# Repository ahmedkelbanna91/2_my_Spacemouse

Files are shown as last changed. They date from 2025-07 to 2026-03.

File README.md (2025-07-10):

# 2_my_Spacemouse
  This ia the best and most interesting project I have been working on. It is a combination of reverse engineering, modification and development of the Spacemouse from 3Dconnexion. I designed the body and this is the code that reads all data from sensors and buttons then send it to the 3DxWare software to use it as same as the original spacemouse compact.

  It is based on Waveshare Esp32S3 Zero board.

  ##Based on this https://github.com/AndunHH/spacemouse

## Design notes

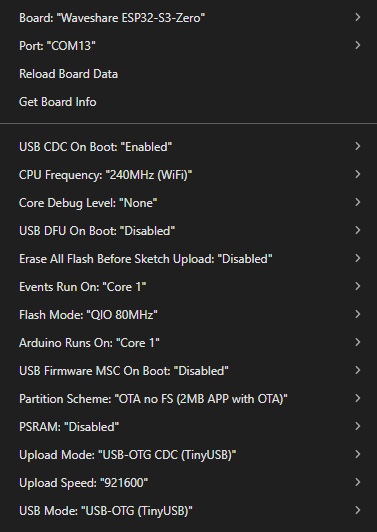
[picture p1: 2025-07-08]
config.jpg

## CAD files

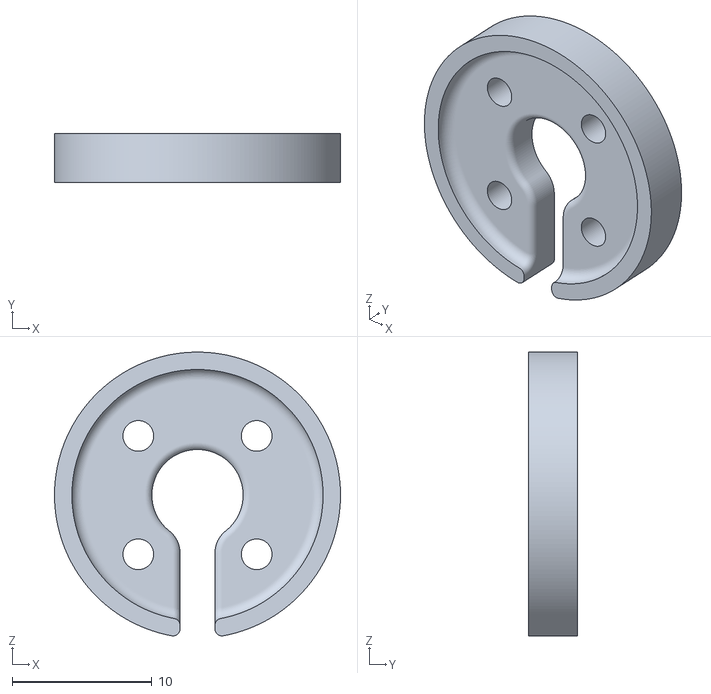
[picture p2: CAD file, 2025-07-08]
3D_Printable_Design_Files/topHolder spacer.stl
20.5 x 3.50 x 20.3

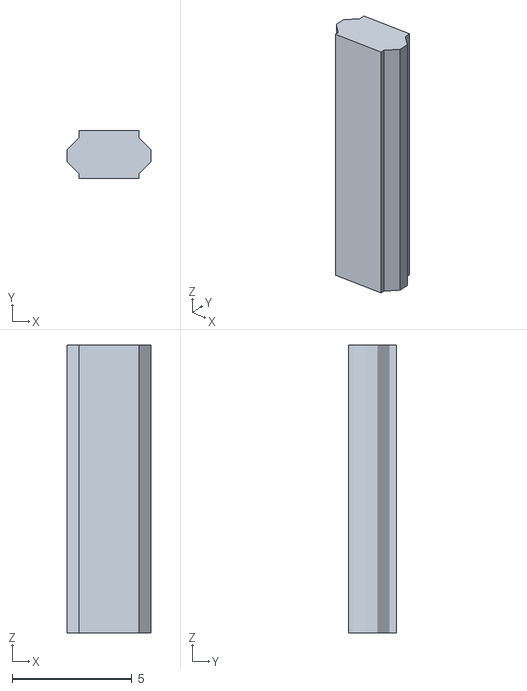
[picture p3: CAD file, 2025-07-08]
3D_Printable_Design_Files/wire-cover.stl
3.50 x 2.00 x 12.0

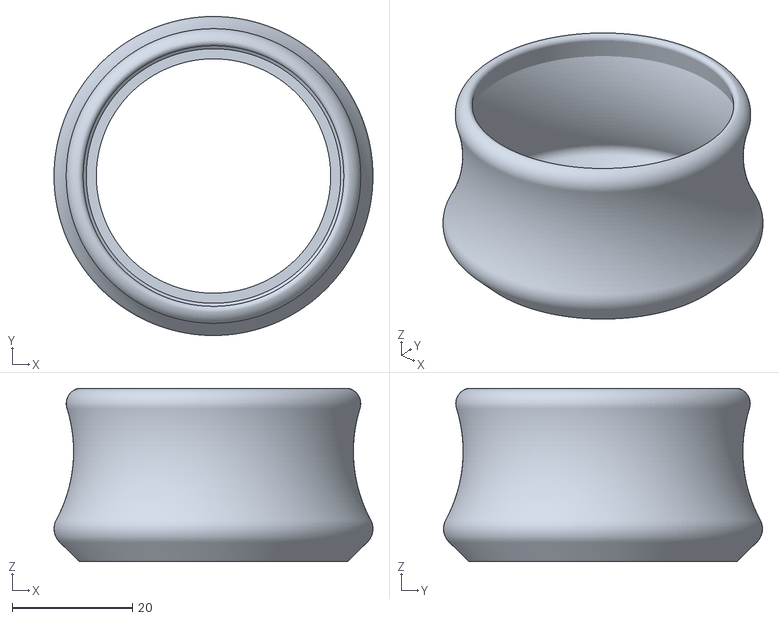
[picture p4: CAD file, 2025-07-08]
3D_Printable_Design_Files/Rubber-Knop.stl
53.1 x 53.1 x 28.8

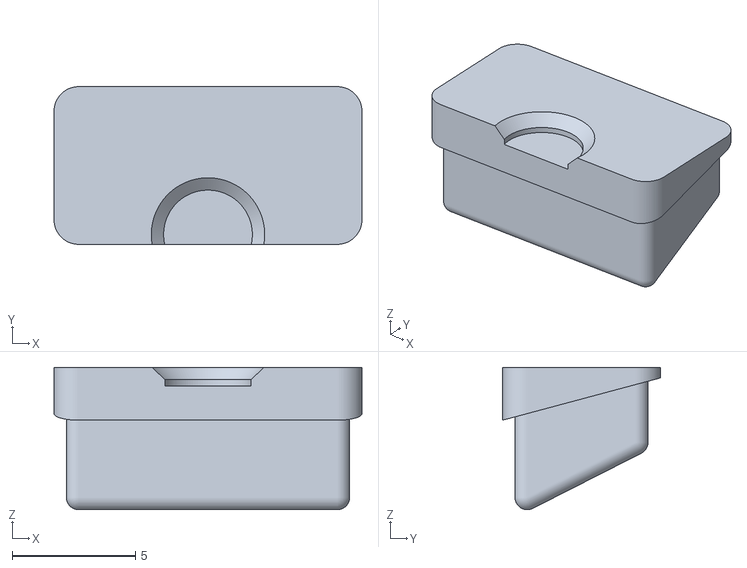
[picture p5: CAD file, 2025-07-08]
3D_Printable_Design_Files/back-btn.stl
12.5 x 6.40 x 5.78

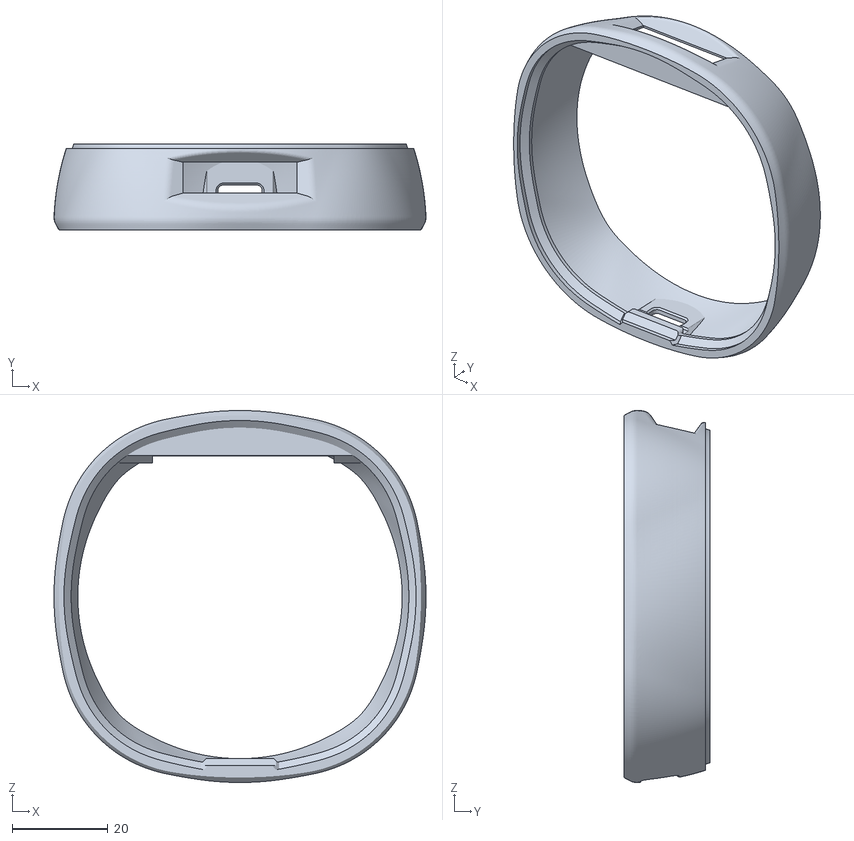
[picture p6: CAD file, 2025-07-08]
3D_Printable_Design_Files/bottom-body.stl
77.9 x 18.1 x 77.9

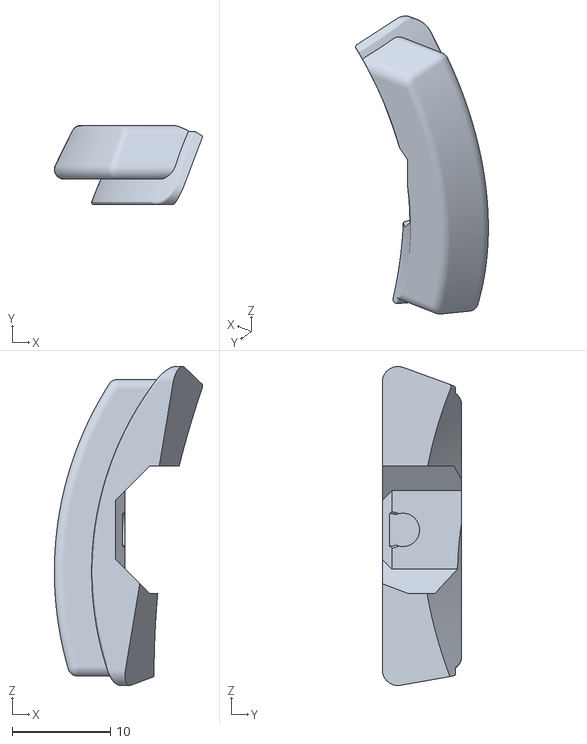
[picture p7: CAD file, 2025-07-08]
3D_Printable_Design_Files/right-btn.stl
15.1 x 8.10 x 32.5

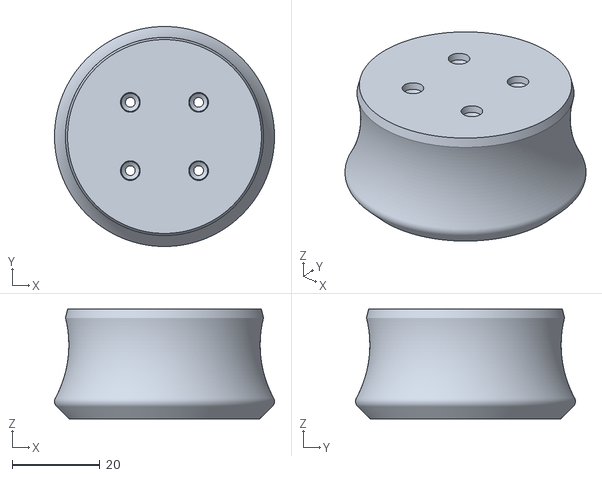
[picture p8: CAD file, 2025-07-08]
3D_Printable_Design_Files/Knop.stl
50.1 x 50.1 x 25.0

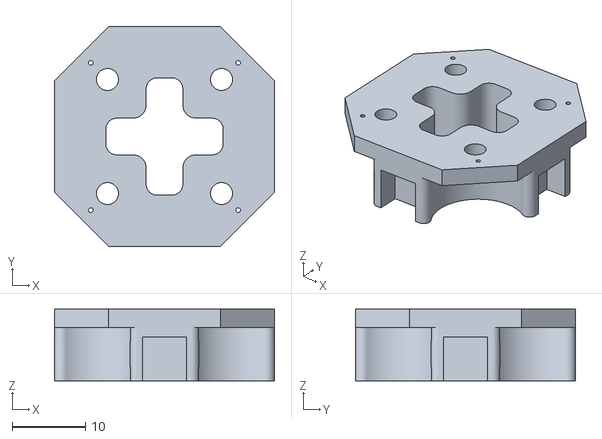
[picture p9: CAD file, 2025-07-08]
3D_Printable_Design_Files/top2.stl
30.0 x 30.0 x 9.80

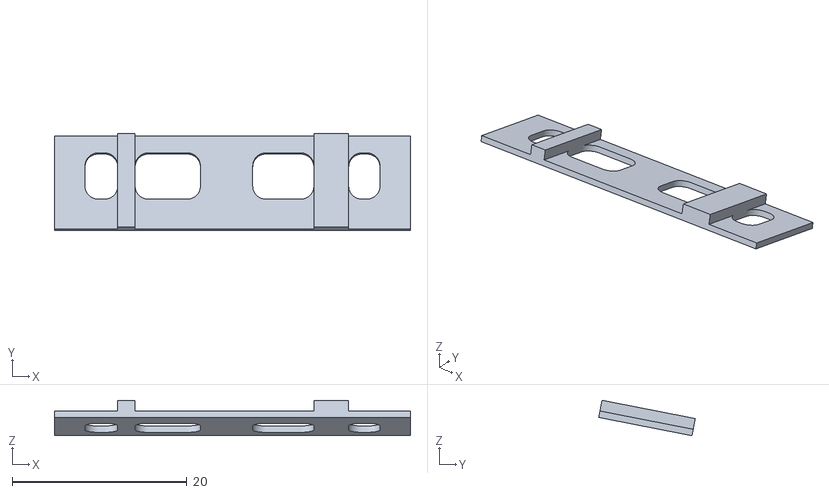
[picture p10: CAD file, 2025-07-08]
3D_Printable_Design_Files/lcd-fixer.stl
40.8 x 11.1 x 4.06

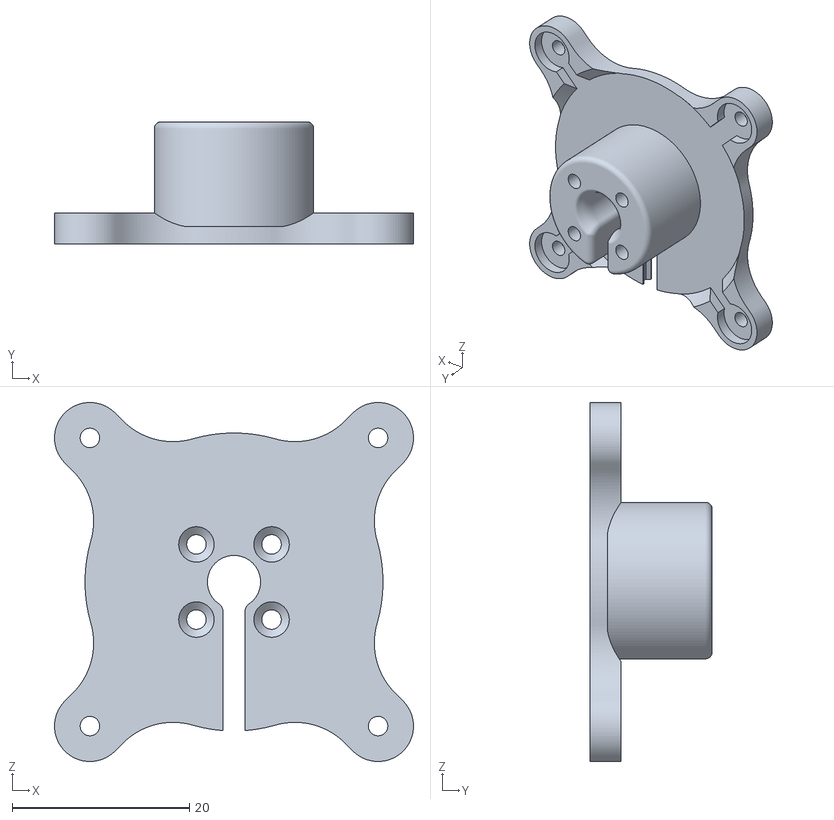
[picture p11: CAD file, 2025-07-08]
3D_Printable_Design_Files/top-holder.stl
40.5 x 13.8 x 40.5

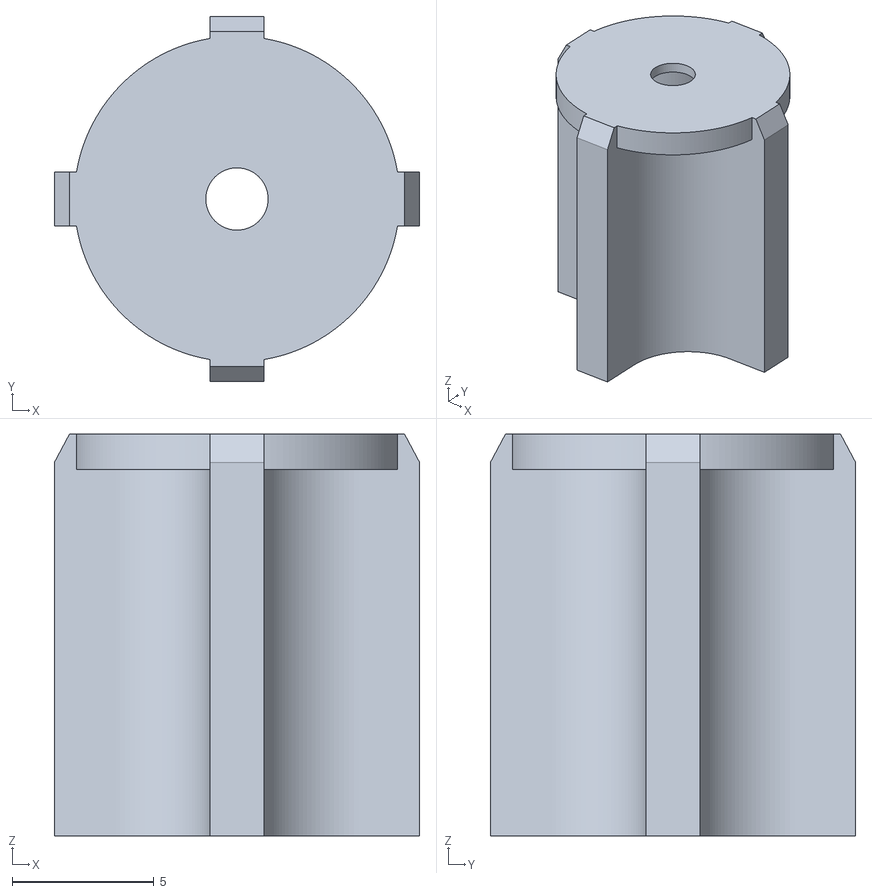
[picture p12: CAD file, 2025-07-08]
3D_Printable_Design_Files/mid2.stl
12.9 x 12.9 x 14.2

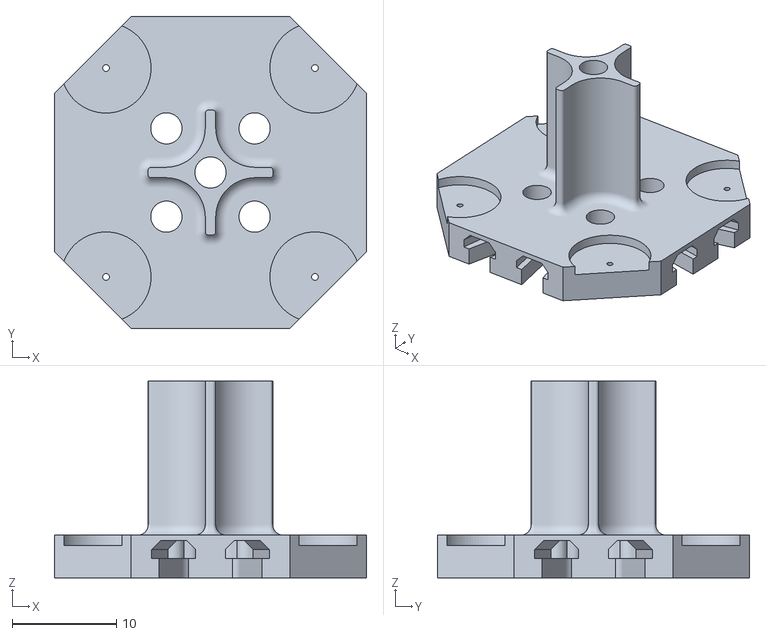
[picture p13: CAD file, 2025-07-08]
3D_Printable_Design_Files/bottom2.stl
30.0 x 30.0 x 18.9

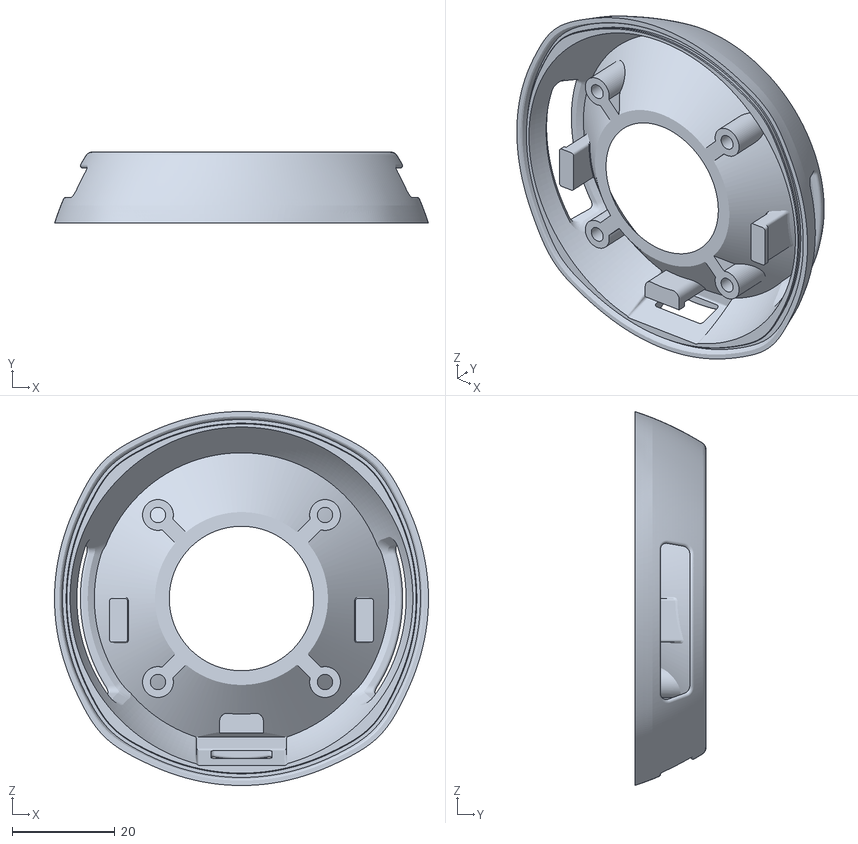
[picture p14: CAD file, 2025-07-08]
3D_Printable_Design_Files/top-body.stl
72.8 x 13.9 x 72.8

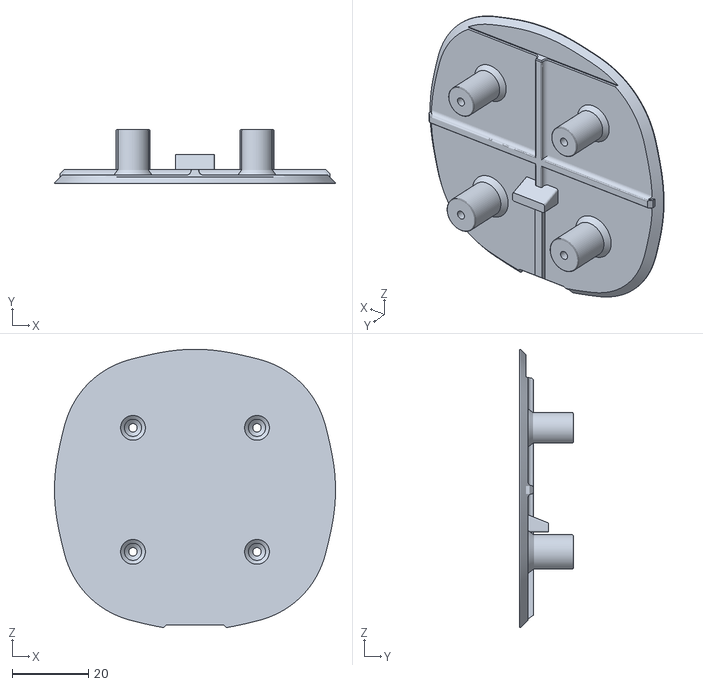
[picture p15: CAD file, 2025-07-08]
3D_Printable_Design_Files/bottom-body-cover.stl
73.7 x 14.1 x 73.0

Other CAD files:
3D_Printable_Design_Files/Left-btn.stl
3D_Printable_Design_Files/knop cover.stl
3D_Printable_Design_Files/esp32-fixer.stl
3D_Printable_Design_Files/Rubber-Knop (1).stl

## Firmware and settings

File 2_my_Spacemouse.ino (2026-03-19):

// #include "Arduino.h"
#include "config.h"
#include "screen.h"
#include "usbSpaceHID.h"
#include "kinematics.h"
#include "calibration.h"
#include "spaceKeys.h"



#ifdef LEDpin
#include "ledring.h"
#endif


// the debug mode can be set during runtime via the serial interface. See config.h for a description of the different debug modes.
int debug = STARTDEBUG;
bool doOnce = true;

// stores the raw analog values from the joysticks
int rawReads[8];

// Centerpoints store the zero position of the joysticks
int centerPoints[8];

// stores the values from the joysticks after zeroing and mapping
int centered[8];

// store raw value of the keys, without debouncing
int keyVals[NUMKEYS];

// key event, after debouncing. It is 1 only for a single sample
uint8_t keyOut[NUMKEYS];
// state of the key, which stays 1 as long as the key is pressed
uint8_t keyState[NUMKEYS];

// Resulting calculated velocities / movements
// int16_t to match what the HID protocol expects.
int16_t velocity[6];



void setup() {
  setupDisplay();
  setupUSB();
  showBootscreen();

  analogReadResolution(analogRead_Resolution);

  setupkalmanFilters();
  busyZeroing(centerPoints, 500, true);
#ifdef LEDpin
  initLEDring();
#endif
  busyZeroing(centerPoints, 3000, true);

  if (!HID.ready()) {
    delay(1);
    return;
  }

// setup the keys e.g. to internal pull-ups
#if NUMKEYS > 0
  setupKeys();
#endif
}

void loop() {
  // check if the user entered a debug mode via serial interface
  if (SERIAL.available()) {
    int tmpInput = SERIAL.parseInt();  // Read from serial interface, if a new debug value has been sent. Serial timeout has been set in setup()
    if (tmpInput != 0) {
      debug = tmpInput;
      if (tmpInput == -1) {
        SERIAL.println(F("Please enter the debug mode now or while the script is reporting."));
      }
    }
  }

  // Joystick values are read. 0-1023
  readAllFromSensors(rawReads);

#if NUMKEYS > 0
  // LivingTheDream added reading of key presses
  readAllFromKeys(keyVals);
#endif
  // Report back 0-1023 raw ADC 10-bit values if enabled
  if (debug == 1) debugOutput1(rawReads, keyVals);

  if (debug == 11 || doOnce) {
    // calibrate the joystick
    // As this is called in the debug=11, we do more iterations.
    busyZeroing(centerPoints, 3000, true);
    debug = -1;  // this only done once
    doOnce = false;
  }

  // Subtract centre position from measured position to determine movement.
  for (int i = 0; i < 8; i++) {
    centered[i] = rawReads[i] - centerPoints[i];
  }

  if (debug == 12) calcMinMax(centered);  // debug=12 to calibrate MinMax values

  // Report centered joystick values if enabled. Values should be approx -500 to +500, jitter around 0 at idle
  if (debug == 2) debugOutput2(centered, keyVals);

  FilterAnalogReadOuts(centered);

  // Report centered joystick values. Filtered for deadzone. Approx -350 to +350, locked to zero at idle
  if (debug == 3) debugOutput2(centered, keyVals);

  calculateKinematic(centered, velocity);

#if NUMKEYS > 0
  evalKeys(keyVals, keyOut, keyState, debug);
#endif

  // Report translation and rotation values if enabled.
  if (debug == 4) debugOutput4(velocity, keyOut);
  if (debug == 5) debugOutput5(centered, velocity);

    // if the kill-key feature is enabled, rotations or translations are killed=set to zero
#if (NUMKILLKEYS == 2)
  // check for the raw keyVal and not keyOut, because keyOut is only 1 for a single iteration. keyVals has inverse Logic due to pull-ups
  // kill rotation
  if (keyVals[KILLROT] == LOW) {
    velocity[ROTX] = 0;
    velocity[ROTY] = 0;
    velocity[ROTZ] = 0;
  }
  // kill translation
  if (keyVals[KILLTRANS] == LOW) {
    velocity[TRANSX] = 0;
    velocity[TRANSY] = 0;
    velocity[TRANSZ] = 0;
  }
#endif

  // report velocity and keys after possible kill-key feature
  if (debug == 6) debugOutput4(velocity, keyOut);

#if SWITCHYZ > 0
  switchYZ(velocity);
#endif

#ifdef EXCLUSIVEMODE
  // exclusive mode
  // rotation OR translation, but never both at the same time
  // to avoid issues with classics joysticks
  exclusiveMode(velocity);
#endif

  // report velocity and keys after Switch or ExclusiveMode
  if (debug == 61) debugOutput4(velocity, keyOut);

  displayScreen(-velocity[ROTX], -velocity[ROTY], velocity[ROTZ],
                velocity[TRANSX], -velocity[TRANSY], -velocity[TRANSZ],
                keyState);

  // update and report the at what frequency the loop is running
  if (debug == 7) updateFrequencyReport();


  // get the values to the USB HID driver to send if necessary
  if (CheckKey3(keyState[2], debug)) sendUSBData(velocity[ROTX], velocity[ROTY], velocity[ROTZ],
                                                 velocity[TRANSX], velocity[TRANSY], velocity[TRANSZ],
                                                 keyState, debug);

  SpaceMouseHID.sendBattery(10, true);

  checkCalibrationCMD(SpaceMouseHID.getLed(), velocity);
}  // end loop()

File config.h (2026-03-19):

/* Calibration instructions
============================
Follow this file from top to bottom to calibrate your space mouse.
You can find some pictures for the calibration process here:
https://github.com/AndunHH/spacemouse/wiki/Ergonomouse-Build#calibration

Debugging Instructions
=========================
To activate one of the following debugging modes, you can either:
- Change STARTDEBUG here in the code and compile again or
- Compile and upload your program. Change to the serial monitor and type the number and hit enter to select the debug mode.

Debug Modes:
------------
-1: Debugging off. Set to this once everything is working.
0:  Nothing...

1:  Output raw joystick values. 0-analogMax_Resolution raw ADC 10-bit values
11: Calibrate / Zero the Spacemouse and get a dead-zone suggestion (This is also done on every startup in the setup())
12: semi-automatic min-max calibration. (Replug/reset the mouse, to enable the semi-automatic calibration for a second time.)
20: print send usb Payload (trans and rot)
21: print send usb Payload (trans)
22: print send usb Payload (rot)
23: print 3rd button send data state
24: print which button is pressed
2:  Output centered joystick values. Values should be approximately -500 to +500, jitter around 0 at idle.
3:  Output centered joystick values. Filtered for deadzone. Approximately -350 to +350, locked to zero at idle, modified with a function.
4:  Output translation and rotation values. Approximately -350 to +350 depending on the parameter.
5:  Output debug 4 and 5 side by side for direct cause and effect reference.
6:  Report velocity and keys after possible kill-key feature
61: Report velocity and keys after kill-switch or ExclusiveMode
7:  Report the frequency of the loop() -> how often is the loop() called in one second?
8:  Report the bits and bytes send as button codes
*/
#define STARTDEBUG 0  // Can also be set over the serial interface, while the program is running!


/* First Calibration: Hall effect sensors pin assignment
==============================================
Default assembly when looking from above on top of the space mouse
 *
 *    back(USB)     resulting axis (not from the single sensors)
 *
 *      7   6              Y+
 *        |                .
 *   8    |    3           .
 *     ---+---        X-...Z+...X+
 *   9    |    2           .
 *        |                .
 *      0   1              Y-
 *

Each sensor is affected by the position of the magnet. If the magnet moves closer to the sensor the output values should decrease.
If you have mounted the magnets upside-down, the values will be inverted.

1. Try to write down the each HES sensor with the corresponding pin number you chose. If you use the PCB version, the pins are shown
   on the silk screen.
2. Compile the script, type 1 into the serial interface and hit enter to enable debug output 1.
3. With the spacemouse in front of you (ie. USB connection at the backside ie. @ north), move the knob from south to north and observe the debug output:
  3.a) HES1 & HES2 both increase when moving the knob north (magnets further away) and decrease when moving the knob south -> Everything is correct.
  3.b) HES1 & HES2 both decrease when moving the knob south (magnets closer by) -> Everything is correct.
  3.c) The sensorpair acts in the opposite direction (ie. increasing when the magnets get closer by ). You probably have mixed up the poles of the magnets.
       Invert the sensorpair in the INVERTLIST.
  3.c) Another output is showing movement: Swap the pins in the PINLIST. This shouldn't happen when the PCB is used. Debugging is rather difficult when
       the spacemouse is assembled, due to the fact that all sensors act on the same movement.

4. Continue with the other sensor pairs. Moving the magnet closer to the sensor should decrease the value.

5. Optimally when not moving the knob, all sensors should output approximately the same value. You can adjuist the values a little bit
   by adjusting the height of the sensor plate using the spacernuts.

5. Repeat this with every axis and every sensor pair until you have a valid PINLIST and maybe an INVERTLIST
*/

// HES1, HES2, HES3, HES4, HES5, HES6, HES7, HES8

// --- Sensor Pin Definitions ---
// ---------M---------
// -------7---6-------
// --7-------------5--
// M-----------------M
// --8-------------4--
// -------1---2-------
// ---------M---------

#define HES1_PIN 6   // Bottom Pair, Sensor 1, left
#define HES2_PIN 7   // Bottom Pair, Sensor 2, right
#define HES3_PIN 8   // Right Pair, Sensor 3, bottom
#define HES4_PIN 9   // Right Pair, Sensor 4, top
#define HES5_PIN 10  // Top Pair, Sensor 5, right
#define HES6_PIN 11  // Top Pair, Sensor 6, left
#define HES7_PIN 12  // Left Pair, Sensor 7, top
#define HES8_PIN 13  // Left Pair, Sensor 8, bottom

#define analogRead_Resolution 12
#define analogMax_Resolution 4096
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

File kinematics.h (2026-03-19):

// This file contains all functions to calculate the kinematics

// The user specific settings, like pin mappings or special configuration variables and sensitivities are stored in config.h.
// Please open config_sample.h, adjust your settings and save it as config.h
#include "config.h"
#include <math.h>
#include <SimpleKalmanFilter.h>
#define sign(x) ((x) < 0 ? -1 : ((x) > 0 ? 1 : 0))  // Define Signum Function


// SECTION HALLEFFECT
// When using HallE sensors in centered or rawValues array
#define HES1 0
#define HES2 1
#define HES3 2
#define HES4 3

#define HES5 4
#define HES6 5
#define HES7 6
#define HES8 7
// !SECTION HALLEFFECT

// Define position in velocity array.
#define TRANSX 0
#define TRANSY 1
#define TRANSZ 2
#define ROTX 3
#define ROTY 4
#define ROTZ 5

// define an array for reading the analog pins of the joysticks, see config.h
int pinList[8] = PINLIST;
int invertList[8] = INVERTLIST;


SimpleKalmanFilter *kalmanFilters[8];
// float KalmanFilterValues[3] = { 5.0, 2.0, 0.01 };
float KalmanFilterValues[3] = { 2.0, 4.0, 0.01 };

void setupkalmanFilters() {
  for (int i = 0; i < 8; i++) {
    // Parameters: Kalman gain for position, Kalman gain for velocity, measurement error
    kalmanFilters[i] = new SimpleKalmanFilter(
      KalmanFilterValues[0],  // measurement error
      KalmanFilterValues[1],  // estimation error
      KalmanFilterValues[2]   // process noise (Q)
    );
  }
}


/// @brief Function to read and store analogue voltages for each joystick axis.
/// @param rawReads pointer to 8 analog values
void readAllFromSensors(int *rawReads) {
  for (int i = 0; i < 8; i++) {
    int filteredValue = kalmanFilters[i]->updateEstimate(analogRead(pinList[i]));
    if (invertList[i] == 1) {
      rawReads[i] = analogMax_Resolution - filteredValue;  // invert the reading
    } else {
      rawReads[i] = filteredValue;
    }
  }
}

// set the min and maxvals from the config.h into real variables
int minVals[8] = MINVALS;
int maxVals[8] = MAXVALS;
// Please do not change this anymore. Use indipendent sensitivity multiplier.
#define TOTALSENSITIVITY 350

/// @brief Takes the centered joystick values, applies a deadzone and maps the values to +/- 350.
/// @param centered pointer to array with 8 centered analog values
void FilterAnalogReadOuts(int *centered) {
  // Filter movement values. Set to zero if movement is below deadzone threshold.
  for (int i = 0; i < 8; i++) {
    if (centered[i] <= DEADZONE && centered[i] >= -DEADZONE) {
      centered[i] = 0;
    } else {
      if (centered[i] > DEADZONE) {  // if the value is smaller 0 ...
        // ... map the values from the [DEADZONE,max] to [0,+350]
        centered[i] = map(centered[i], DEADZONE, maxVals[i], 0, TOTALSENSITIVITY);
      } else {  // if the value is > 0 ...
        // ... map the value from the [min,-DEADZONE] to [-350,0]
        centered[i] = map(centered[i], minVals[i], -DEADZONE, -TOTALSENSITIVITY, 0);
      }
    }
  }
}

void _calculateKinematicSensors(int *centered, int16_t *velocity) {

  // calculate sensors transX
  velocity[TRANSX] = (centered[HES2] - centered[HES1] + centered[HES5] - centered[HES6]) / 2;

  // calculate sensors transY
  velocity[TRANSY] = (centered[HES3] - centered[HES4] + centered[HES8] - centered[HES7]) / 2;

  // calculate sensors transZ
  velocity[TRANSZ] = (centered[HES1] + centered[HES2] + centered[HES3] + centered[HES4] + centered[HES5] + centered[HES6] + centered[HES7] + centered[HES8]) / 4;

  // rotX
  velocity[ROTX] = (centered[HES1] + centered[HES2] - centered[HES5] - centered[HES6]) / 2;

  // rotY
  velocity[ROTY] = (centered[HES7] + centered[HES8] - centered[HES3] - centered[HES4]) / 2;

  // rotZ
  velocity[ROTZ] = (centered[HES1] + centered[HES3] + centered[HES5] + centered[HES7] - centered[HES2] - centered[HES4] - centered[HES6] - centered[HES8]) / 4;
}

/// @brief Function to modify the input value according to different mathematic modes. Choose the mathematical function in config.h as modFunc
/// @param x input between -350 and +350
/// @return output between -350 and +350
int modifierFunction(int x) {
  // making sure function input never exedes range of -350 to 350
  x = constrain(x, -350, 350);
  double result;
#if (MODFUNC == 1)
  // using squared function y = x^2*sign(x)
  result = 350 * pow(x / 350.0, 2) * sign(x);  // sign putting out -1 or 1 depending on sign of value. (Is needed because x^2 will always be positive)
#elif (MODFUNC == 2)
  // using tan function: tan(x)
  result = 350 * tan(x / 350.0);
#elif (MODFUNC == 3)
  // using squared tan function: tan(x^2*sign(x))
  result = 350 * tan(pow(x / 350.0, 2) * sign(x));  // sign putting out -1 or 1 depending on sign of value. (Is needed because x^2 will always be positive)
#elif (MODFUNC == 4)
  // using cubed tan function: tan(x^3)
  result = 350 * tan(pow(x / 350.0, 3));
#else
  // MODFUNC == 0 or others...
  // no modification
  result = x;
#endif

  // make sure values between-350 and 350 are allowed
  result = constrain(result, -350, 350);
  // converting doubles to int again
  return (int)round(result);
}
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
